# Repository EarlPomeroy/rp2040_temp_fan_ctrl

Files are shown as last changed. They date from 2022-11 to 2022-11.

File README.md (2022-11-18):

# rp2040_temp_fan_ctrl

Fan Controller based around an RP2040 microcontroller

The LCD uses GPIO pins 4 and 5 for i2c output. The LED output is removed in the latest code and is only for debugging and testing. If you need the LCD, uncomment the code and recompile.

The relay I'm using is a JZC-11F controlled with GPIO pin 6. Setting the pin high closes the relay and enables the fans. The LED in the schematic is to dissipate the current when the coil is de-energized.

The fan’s power goes through the normally open pin to common on the relay. Energizing the coil closes the relay and powers the fans.

I’ve set the fan temperature to 50 ℃ as the idle cluster runs about 45 ℃.

# To Build project

```bash
$ cargo build --release
```

# To Flash the RP2040

Hold **BOOTSEL** button and connect to USB

Once mounted, run:

```bash
$ cargo run --release
```

_Note_: This requires the elf2uf2-rs cargo plugin. Install this using:

```bash
$ cargo install elf2uf2-rs
```

See [JoNil/elf2uf2-rs](https://github.com/JoNil/elf2uf2-rs) for code and details.

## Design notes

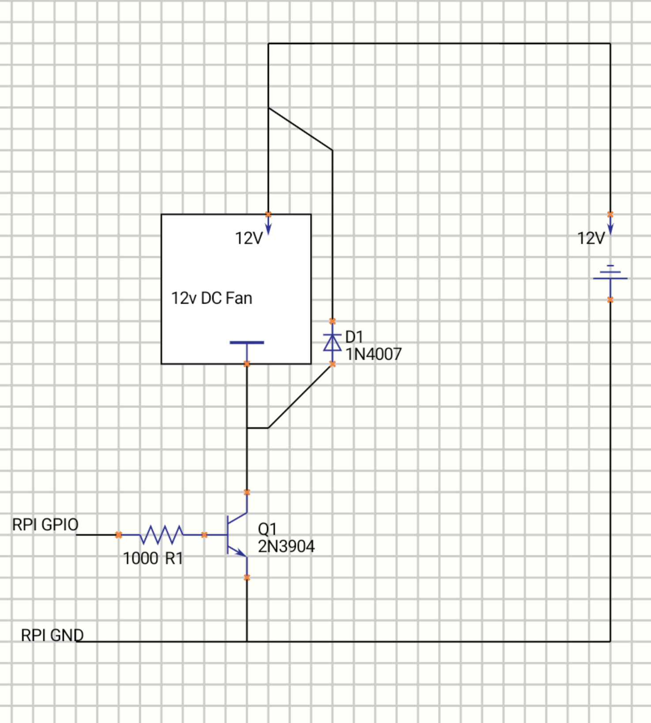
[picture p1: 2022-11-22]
fan_circuit.png

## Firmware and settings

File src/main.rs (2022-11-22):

//! # Control fans for a Raspberry Pi cluster
//!
//! This application uses a Raspberry pico to measure temperature and a relay to control fans
//!
//! It may need to be adapted to your particular board layout and/or pin assignment.
//!
//! See the `Cargo.toml` file for Copyright and license details.

// Code based on:
// https://how2electronics.com/read-temperature-sensor-value-from-raspberry-pi-pico/
// https://docs.sunfounder.com/projects/thales-kit/en/latest/thermometer.html
//

#![no_std]
#![no_main]

// (Uncomment for LCD)
// mod write_to;
// use crate::write_to::write_to::show;

// Ensure we halt the program on panic
use panic_halt as _;

// Some traits we need
use embedded_hal::adc::OneShot;
use embedded_hal::digital::v2::OutputPin;

// (Uncomment for LCD)
// use fugit::RateExtU32;

// Alias for our HAL crate
use rp2040_hal as hal;

// A shorter alias for the Peripheral Access Crate, which provides low-level
// register access
use hal::{pac, Clock};

/// The linker will place this boot block at the start of our program image. We
/// need this to help the ROM boot loader get our code up and running.
/// Note: This boot block is not necessary when using a rp-hal based BSP
/// as the BSPs already perform this step.
#[link_section = ".boot2"]
#[used]
pub static BOOT2: [u8; 256] = rp2040_boot2::BOOT_LOADER_GENERIC_03H;

/// External high-speed crystal on the Raspberry Pi Pico board is 12 MHz. Adjust
/// if your board has a different frequency
const XTAL_FREQ_HZ: u32 = 12_000_000u32;

/// Entry point to our bare-metal application.
///
/// The `#[rp2040_hal::entry]` macro ensures the Cortex-M start-up code calls this function
/// as soon as all global variables and the spin lock are initialized.
///
/// The function configures the RP2040 peripherals, then performs a single I²C
/// write to a fixed address.
#[rp2040_hal::entry]
fn main() -> ! {
    let mut pac = pac::Peripherals::take().unwrap();
    let core = pac::CorePeripherals::take().unwrap();

    // Set up the watchdog driver - needed by the clock setup code
    let mut watchdog = hal::Watchdog::new(pac.WATCHDOG);

    // Configure the clocks
    let clocks = hal::clocks::init_clocks_and_plls(
        XTAL_FREQ_HZ,
        pac.XOSC,
        pac.CLOCKS,
        pac.PLL_SYS,
        pac.PLL_USB,
        &mut pac.RESETS,
        &mut watchdog,
    )
    .ok()
    .unwrap();

    // The single-cycle I/O block controls our GPIO pins
    let sio = hal::Sio::new(pac.SIO);

    // Set the pins to their default state
    let pins = hal::gpio::Pins::new(
        pac.IO_BANK0,
        pac.PADS_BANK0,
        sio.gpio_bank0,
        &mut pac.RESETS,
    );

    // Configure two pins as being I²C, not GPIO (Uncomment for LCD)
    // let sda_pin = pins.gpio4.into_mode::<hal::gpio::FunctionI2C>();
    // let scl_pin = pins.gpio5.into_mode::<hal::gpio::FunctionI2C>();

    let mut fan_ctrl_pin = pins.gpio6.into_push_pull_output();

    // Enable ADC
    let mut adc = hal::Adc::new(pac.ADC, &mut pac.RESETS);

    // Enable the temperature sense channel
    let mut temperature_sensor = pins.gpio28.into_floating_input();

    // Create the I²C drive, using the two pre-configured pins. This will fail
    // at compile time if the pins are in the wrong mode, or if this I²C
    // peripheral isn't available on these pins!
    // (Uncomment for LCD)
    // let mut i2c = hal::I2C::i2c0(
    //     pac.I2C0,
    //     sda_pin,
    //     scl_pin, // Try `not_an_scl_pin` here
    //     400.kHz(),
    //     &mut pac.RESETS,
    //     &clocks.system_clock,
    // );

    let mut delay = cortex_m::delay::Delay::new(core.SYST, clocks.system_clock.freq().to_Hz());

    // (Uncomment for LCD)
    // let mut lcd = lcd_lcm1602_i2c::Lcd::new(&mut i2c, &mut delay)
    //     .address(0x27)
    //     .cursor_on(false) // no visible cursors
    //     .rows(2) // two rows
    //     .init()
    //     .unwrap();

    // The 12-bit ADC pin reading is between 0 and 4096 for thermistor
    let conversion_factor = 3.3 / 4096.0;
    let resistor_val: f64 = 10000.0;
    fan_ctrl_pin.set_low().unwrap();

    // (Uncomment for LCD)
    // lcd = lcd.init().unwrap();
    // lcd.clear().unwrap();

    loop {
        // read 12-bit value and convert to some percentage of the 3.3v
        let adc_temp_value: u16 = adc.read(&mut temperature_sensor).unwrap();
        let voltage: f64 = adc_temp_value as f64 * conversion_factor;

        let resistance = resistor_val * voltage / (3.3 - voltage);
        // get temp kelvin
        let temp_k = 1.0
            / (((libm::log(resistance as f64 / resistor_val)) / 3950.0) + (1.0 / (273.15 + 25.0)));

        // convert to Celsius
        let temp = temp_k - 273.15;

        // Set to 50 C for fans on. Use 25 C for testing with body temp.
        if temp > 50.0 {
            fan_ctrl_pin.set_high().unwrap();
            // leave the fan on for one minutes before checking again
            // Comment this out for LCD and the lcd_lcm1602_i2c takes ownership of the delay.
            delay.delay_ms(60000);
        } else {
            fan_ctrl_pin.set_low().unwrap();

            // Delay 15 seconds between measurements
            // Comment this out for LCD and the lcd_lcm1602_i2c takes ownership of the delay.
            delay.delay_ms(15000);
        }

        // (Uncomment for LCD)
        // let mut buf = [0u8; 64];

        // lcd.set_cursor(0, 0).unwrap();
        // let output: &str = show(&mut buf, format_args!("Temp: {}", temp)).unwrap();
        // lcd.write_str(output).unwrap();

        // lcd.set_cursor(1, 0).unwrap();
        // let output: &str = show(&mut buf, format_args!("Pin val: {}", adc_temp_value)).unwrap();
        // lcd.write_str(output).unwrap();
    }
}

// End of file

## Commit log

2022-11-18 Initial commit
    Basic logic in place for controlling fans via relay
    LCD output included for debugging and validation of temp
    [fan_ctrl.fzz, fan_ctrl_with_led.fzz]
2022-11-18 First pass at code used on board.
    Temp set to 50 C for fans on
    Commented out LCD code
2022-11-22 Fixed circuit files, updated MCU code
    Fritizing files updated to something that works.
    Added circuit.png in case fzz files are unclear (or wrong)
    Added a 1 minute delay once fans are on. Else turn fans off and wait 15
    secs till checking again.
    [fan_ctrl.fzz, fan_ctrl_with_led.fzz]
